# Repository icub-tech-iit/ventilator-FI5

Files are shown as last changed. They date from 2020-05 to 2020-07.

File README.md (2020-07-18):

FI5 Ventilator
==============
This repository contains the electronics of the ventilator.

### :file_folder: Folder organization
This repository is organized as follows:
- 🔘 `electrical_scheme` contains the electrical schematic of the ventilator (Logic diagram).
- 🔘 `electronic_boards` contains the OrCad schematics of the custom boards used in the ventilator, the gerber files for the PCBs, and the bill of material.
- 🔘 `wiring` contains the wiring diagram and the harness bill of material of the ventilator.

## Electronics repository
To correctly manage the large files stored within this repository, follow the [instructions to install Git LFS][1].

You can conveniently download the Electronics releases by visiting the [Release Page][2] 📦

[1]: https://help.github.com/en/articles/installing-git-large-file-storage
[2]: ../../releases

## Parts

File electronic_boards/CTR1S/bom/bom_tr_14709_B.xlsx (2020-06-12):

ID | IITCODE | N.P | QTY | REFDES | PACKAGE | CATEGORY | Value | Supply_voltage | Tolerance | Pieces_quoted | Description | Manuf | Manuf Code
1 | 579 |  | 1,00 | U4 | SOT23-5 | AO | LMC7101-BIM5 | 2.715V |  |  | Operational Amplifier, single, 2.715V supply voltage, rail to rail output swing, SMD, SOT23-5 | National Semiconductor | LMC7101-BIM5
2 | 14700 |  | 1,00 | U3 | 4132 | AP | 4132 |  |  |  | GPIO Expander module, 16 Additional IO over I2C, for Raspberry PI | Adafruit | 4132
3 | 14701 |  | 2,00 | U1 U5 | 3190 | AP | 3190 |  |  |  | Brushed DC Motor Driver Breakout, Adafruit | Adafruit | 3190
4 | 14703 |  | 1,00 | M7 | - | AP | STM32F746G-DISCO |  |  |  | ARM 32F746G, Discovery Kit ARMÂ® CortexÂ®-M7 Embedded Evaluation Board | St microelectronics | STM32F746G-DISCO
5 | 3 |  | 3,00 | C16 C15 C13 | 0603 | C | 100nF | 50V | 10% | X7R | Multilayer Ceramic Capacitor, 100nF, 50V, 10%, X7R, SMD, 0603 | Kemet | C0603C104K5RAC7867
6 | 652 |  | 1,00 | C14 | 0603 | C | 33nF | 50V | 5% | X7R | Multilayer Ceramic Capacitor, 33nF, 50V, 5%, X7R, SMD, 0603 | Avx | 06035C333JAT2A
7 | 7120 |  | 12,00 | C12 C11 C10 C9 C8 C7 C6 C5 C4 C3 C2 C1 | 0603 | C | 10nF | 25V | 5% | C0G | Multilayer Ceramic Capacitor, 10nF, 25V, 5%, C0G, SMD, 0603 | Kemet | C0603C103J3GACTU
8 | 274 |  | 5,00 | J24 J23 J22 J21 J20 | MKDS12-381 | CO | MKDS 12-3.81 | 12A |  |  | Terminal block, MKDS, 2 contacts, 1 row, female, p.3.81mm, Straight, w to b, 12A, screw terminal, THD | Phoenix | 1727010
9 | 275 |  | 2,00 | J28 J14 | MKDS13-381 | CO | MKDS 13-3.81 | 12A |  |  | Terminal block, MKDS, 3 contacts, 1 row, female, p.3.81mm, Straight, w to b, 12A, screw terminal, THD | Phoenix | 1727023
10 | 288 |  | 2,00 | J17 J5 | 53261-0471 | CO | 53261-0471 | 1A |  |  | PCB connector, Picoblade, 4 contacts, 1 row, male, p.1.25mm, 90Â°, w to b, lock, key, SMD | Molex | 53261-0471
11 | 504 |  | 3,00 | TP3 TP1 TP2 | TP-1206 | CO | S1751-46 |  |  |  | Test point, SMD, 1206 | Harwin | S1751-46
12 | 628 |  | 1,00 | J11 | PSTRIP5X1_M | CO | M20-9990545 | 3A |  |  | PCB connector, Pin strip, 5 contacts, 1 row, male, p.2.54mm, Straight, b to b, nolock, nokey, THD | Harwin | M20-9990545
13 | 709 |  | 3,00 | J32 J27 J18 | 53261-0871 | CO | 53261-0871 | 1A |  |  | PCB connector, Picoblade, 8 contacts, 1 row, male, p.1.25mm, 90Â°, w to b, nolock, key, SMD | Molex | 53261-0871
14 | 805 |  | 1,00 | J3 | PSTRIP6X1_M | CO | M20-9990645 | 3A |  |  | PCB connector, Pin strip, 6 contacts, 1 row, male, p.2.54mm, Straight, b to b, nolock, nokey, THD | Harwin | M20-9990645
15 | 1124 |  | 3,00 | J12 J9 J7 | 53261-0671 | CO | 53261-0671 | 1A |  |  | PCB connector, Picoblade, 6 contacts, 1 row, male, p.1.25mm, 90Â°, w to b, nolock, key, SMD | Molex | 53261-0671
16 | 1210 |  | 2,00 | J16 J6 | 53398-0471 | CO | 53398-0471 | 1A |  |  | PCB connector, Picoblade, 4 contacts, 1 row, male, p.1.25mm, Straight, w to b, nolock, key, SMD | Molex | 53398-0471
17 | 1388 |  | 3,00 | J13 J10 J8 | 53398-0671 | CO | 53398-0671 | 1A |  |  | PCB connector, Picoblade, 6 contacts, 1 row, male, p.1.25mm, Straight, w to b, nolock, key, SMD | Molex | 53398-0671
18 | 1391 |  | 2,00 | J31 J19 | 53398-0871 | CO | 53398-0871 | 1A |  |  | PCB connector, Picoblade, 8 contacts, 1 row, male, p.1.25mm, Straight, w to b, nolock, key, SMD | Molex | 53398-0871
19 | 12787 |  | 2,00 | J4 J1 | PSTRIP8X1_M | CO | M20-9990445 | 3A |  |  | PCB connector, Pin strip, 8 contacts, 1 row, male, p.2.54mm, Straight, b to b, nolock, nokey, THD | Harwin | M20-9990845
20 | 13911 |  | 1,00 | J2 | PSTRIP10X1_M | CO | TSW-110-07-G-S | 5.7A |  |  | PCB connector, Pin strip, 10 contacts, 1 row, male, p.2.54mm, straight, b to b, nolock, nokey, THD | Samtec | TSW-110-07-G-S
21 | 14713 |  | 2,00 | J30 J29 | - | COPF | 642-4957 | 1A |  |  | Flying connector, IDC, 16 contacts, 2 rows, female, p.2.54mm, Straight, w to w, no lock, key, 1A | RS | 642-4957
22 | 5126 |  | 1,00 | U8 | JHM10D | DC | JHM1012D05 | 10W | 10% |  | Insulated, DCDC converter, Vin 918V, Vout +-5V, 10W, insulation 4KVdc, THD, DIP, for medical use | Xp power | JHM1012D05
23 | 617 |  | 2,00 | D2 D1 | DO214AA | DI | SL22 | 2A |  |  | Diode schottky, Vrrm 20V, If 2A, Ifms 100A, SMD, DO214AA | Vishay | SL22
24 | 14710.0 |  | 1,00 | PCB |  | PCB | CTR1S_00 |  |  |  | CTR1S_00, IIT - Printed Circuit board | IIT | 14707
25 | 242 |  | 3,00 | R33 R32 R2 | 0603 | R | 0R | 0.063W | 1% | 200ppm | Resistor Thick film, 0R, 0.063W, 1%, SMD, 0603 | Multicomp | MC-0.063W-0603-0R
26 | 245 |  | 9,00 | R13 R14 R15 R19 R20 R21 R22 R23 R31 | 0603 | R | 1K | 0.1W | 1% | 100ppm | Resistor Thick Film, 1K, 0.1W, 1%, SMD, 0603 | Phycomp | 232270461002
27 | 447 |  | 2,00 | R16 R18 | 0603 | R | 220R | 0.1W | 1% | 100ppm | Resistor Thick film, 220R, 0.1W, 1%, SMD, 0603 | Phycomp | RC0603FR-07220RL
28 | 453 |  | 1,00 | R29 | 0603 | R | 1K2 | 0.1W | 1% | 200ppm | Resistor Thick film, 1K2, 0.1W, 1%, SMD, 0603 | Phycomp | RC0603FR-071K2L
29 | 454 |  | 1,00 | R30 | 0603 | R | 1K5 | 0.1W | 1% | 100ppm | Resistor Thick film, 1K5, 0.1W, 1%, SMD, 0603 | Phycomp | RC0603FR-071K5L
30 | 455 |  | 1,00 | R28 | 0603 | R | 2K2 | 0.1W | 1% | 100ppm | Resistor Thick film, 2K2, 0.1W, 1%, SMD, 0603 | Phycomp | RC0603FR-072K2L
31 | 462 |  | 1,00 | R27 | 0603 | R | 15K | 0.1W | 1% | 100ppm | Resistor Thick film 15K, 0.1W, 1%, SMD, 0603 | Phycomp | RC0603FR-0715KL
32 | 1574 |  | 11,00 | R5 R6 R7 R8 R9 R10 R11 R17 R24 R34 R35 | 0603 | R | 10K | 0.063W | 1% | 100ppm | Resistor Thick film, 10K, 0.063W, 1%, SMD, 0603 | Multicomp | MC 0.063W 0603 1% 10K
33 | 12058 |  | 4,00 | R42 R43 R44 R45 | 6.3X2.3 | R | 100R | 0.5W | 5% | 700ppm | Resistor Carbon film, 100R, 0.5W, 5%, THD, Diam 6.3x2.3mm | RS | 707-8142
34 | 14702 |  | 1,00 | U2 | 1536 | SE | Buzzer 5V |  |  |  | Miniature piezo buzzer, for Adafruit breadboard, 2kHz, 35V, THD | Adafruit | 1536
35 | 5232 | X | 25,00 | TP28 TP25 TP26 TP27 TP23 TP24 TP20 TP21 TP22 TP18 TP19 TP15 TP16 TP17 TP13 TP14 TP10 TP11 TP12 TP8 TP9 TP5 TP6 TP7 TP4 | TP-ATE, TP-ATE-TH, TP-ATE-SMALL, TP-ATE_1MM | CO | TEST POINT 3mm |  |  |  | Test point, PCB, round, 3mm, for automatic test equipment | IIT | 5232
36 | 4270 | X | 4,00 | H4 H3 H2 H1 | MH3 | FAST | M3 Metallized hole |  |  |  | PCB hole, metallized, for M3 thread | IIT | 4270
37 | 242 | X | 6,00 | R37 R38 R39 R40 R41 R4 | 0603 | R | 0R | 0.063W | 1% | 200ppm | Resistor Thick film, 0R, 0.063W, 1%, SMD, 0603 | Multicomp | MC-0.063W-0603-0R
38 | 289 | X | 1,00 | R1 | 0805 | R | 0R | 0.125W | 1% | 200ppm | Resistor Thick Film, 0R, 0.125W, 1%, SMD, 0805 | Phycomp | 232273091002

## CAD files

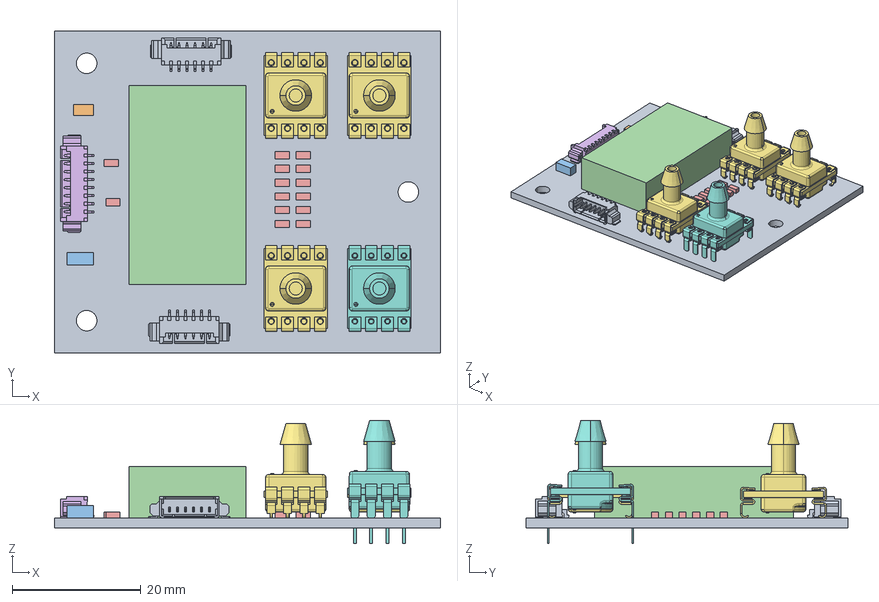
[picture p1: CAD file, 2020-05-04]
electronic_boards/CTR1P/mcad/CTR1P_00.stp
60.0 x 50.0 x 19.2 mm
ASM0002
TP-1206
PICOBLADE-8X1-MALE90-P125
HSCMAND160MD2A5 x 3
HSCDANN150PG2A5
PICOBLADE-6X1-MALE90-P125 x 2

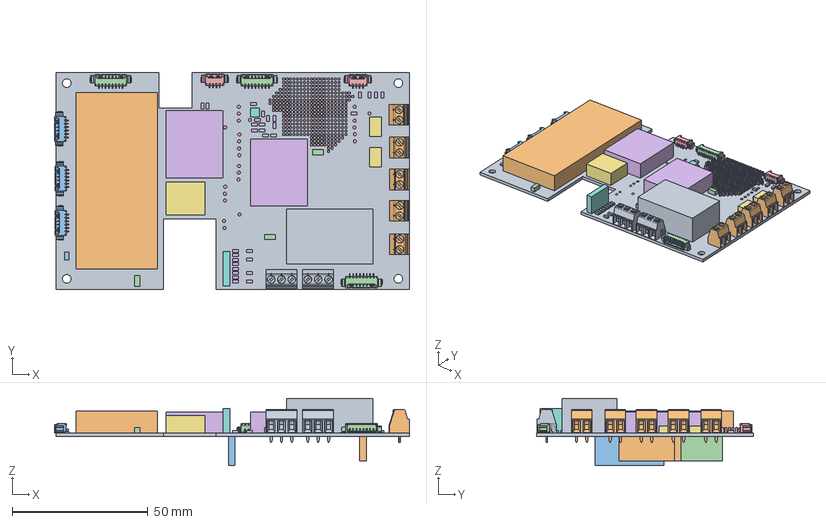
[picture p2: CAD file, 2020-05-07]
electronic_boards/CTR1S/mcad/CTR1S.stp
130.6 x 80.0 x 24.8 mm
PCB_CTR1S_00_MECH
PSTRIP8X1_M x 2
PSTRIP10X1_M
PSTRIP6X1_M
TP-ATE-TH x 369
DO214AA x 2
PSTRIP5X1_M
MKDS13-381 x 2
MKDS12-381 x 5
TP-1206 x 3
TP-ATE x 25
SOT23-5
JHM10D
PICOBLADE-6X1-MALE90-P125 x 3
PICOBLADE-8X1-MALE90-P125 x 3
PICOBLADE-4X1-MALE90-P125 x 2

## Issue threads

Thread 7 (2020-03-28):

Define the power supply

MrAndrea, 2020-03-28:
Ventilator needs a power supply. In this issue we collect proposals to find a good solution.
Action points:
- [ ] estimate the power consumption of the ventilator
- [x] evaluate battery solution / UPS for backup of the mains voltage
- [ ] other (WIP)

maggia80, 2020-05-27:
we need to change the value of R28 for setting the shutdown threshold

R28 was 51k become 82k

maggia80, 2020-05-27:
R10 and R11 are now 51k. Now the battery voltage and the output voltage is 13.60V.

MrAndrea, 2020-05-28:
I added the charger on the logic schematic, @maggia80 is the connection corresponding to the cabling?

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

MrAndrea, 2020-06-25:
`Rev 0.0.6` (logic and harness) contains the charger connections as proposed in the [previous comment](https://github.com/icub-tech-iit/ventilator-FI5/issues/7#issuecomment-635360759).

Closed 2023-01-04.

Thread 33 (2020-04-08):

FW design and implementation notes

andreamerello, 2020-04-08:
In this issue we are going to publishing some misc notes we wrote in EDL regarding firmware design and implementation proposal. They include architectural aspects and notes about HW configuration.

They are still **draft**, but we would like to start sharing something; they are about the low level part (sensor reading/pwm generation).

pattacini, 2020-05-13:
We're certainly done with this, you guys having done a great job 👍
Further refinements and bug fixes can be conveniently made in dedicated issues.

Closed 2020-05-13.

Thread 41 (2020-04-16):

Design the electrical schematic with Capital

MrAndrea, 2020-04-16:
This issue to create and describe the electrical schematic of the ventilator using Mentor Capital.

MrAndrea, 2022-10-19:
I think we can close this issue.

Closed 2022-10-19.

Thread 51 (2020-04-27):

Alarms to be implemented in FSM

simeonedussoni, 2020-04-27:
Here we collect needed alarms to be implemented in the ventilator. Related signals, sensors etc. will be read by a dedicated FSM which will be in charge of generating the corresponding buzzer/light conditions as well as to pass infos to the controller. Many alarms are already discussed in several places.

simeonedussoni, 2021-11-05:
project closed, I close also the issue.

Closed 2021-11-05.

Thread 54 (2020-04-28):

Create BOMs

MrAndrea, 2020-04-28:
In this issue we collect the BOMs of the ventilator for the electronics and the wiring as the work progresses.
The BOMs will be upload on Wingst with the respective IITCODE.

Closed 2020-05-13.

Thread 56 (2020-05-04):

Develop GUI menu dialogs

Nicogene, 2020-05-04:
# Task description
This issue keeps track of the development of the menu functionalities for the ventilator GUI.

# Definition of Done
The menu functionalities are fully implemented.

pattacini, 2020-05-24:
Instead of using the touch screen, we need to anchor the menu dialogs to the use of the multi-selector encoder. The tags and the ranges of the dialog options can be retrieved by inspecting the FSM.

Closed 2023-01-04.

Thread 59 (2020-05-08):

Download data from FI5 to do comparative analyses

pattacini, 2020-05-08:
We need to download experimental data from FI5 in order to be able to carry out extensive analyses to validate the device and the simulation predictions.

@marcoaccame can this be done relying merely on the debugger or do we need to design some sort of rudimental acquisition layer?

marcoaccame, 2020-05-13:
Hi @pattacini, we don't need to buffer data in RAM.

We have two solutions:
- use the trace port, which I have already used to print data at every 10 ms. it is textual data which i can format as i like.
- use the usart with an increased sped. i have just tested a speed of  20x=112500 and I read correctly w/ putty.

In following days I will write and test a proper data dumper.

marcoaccame, 2020-06-17:
just committed code for performing data log: https://github.com/icub-tech-iit/ventilator-FI5/commit/979b7d7a203667c4bb624f9fec48b8f96b6cc722. it is possible to use either trace port of usart @ 4mbps.
tests + data collection: tomorrow.

pattacini, 2020-06-18:
Analyses carried out in #60 confirm that this acquisition methodology is effective and up to the task.

@marcoaccame we can close this, I reckon.

Closed 2020-06-18.

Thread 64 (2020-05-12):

Error in BIVAR CODE for yellow and green panel LEDs in partlist

claudiolorini, 2020-05-12:
~~Partlist~~

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

pattacini, 2020-05-13:
@claudiolorini just a brief note: now that the repo's been made public we should no longer post links to restricted resources. Thus, I've edited your OP above with a screenshot (the quickest solution that I had).

claudiolorini, 2020-05-14:
whoever compiled the partlist, i suppose @Fabrizio69? btw after some navigation in the project (tree and branches) i wasn't able to find the position of the partlist in the git repository, a more visible handle can be advantageous...

pattacini, 2020-05-14:
Given the [structure of the repo][1], the [BOM][2] is located in the `mech` branch, if that is the resource you meant.

At any rate, we should devote some effort to enrich the repo with `README.md` files describing the resources we made openly available as we've just gone public. In this sense, yep, we kind of still lack this type of documentation.

Anyway, @Fabrizio69 would you be willing to fix this bug in the BOM? Be careful as the `mech` branch is revisioned under Git LFS, although Excel files are not tracked by LFS (yet).

[1]: ../../ventilator-FI5#-repository-structure
[2]: https://github.com/icub-tech-iit/ventilator-FI5/blob/mech/Ventilator%20FI5%20BOM%20Rev0.xlsx

maggia80, 2020-05-20:
I have updated the BOM:

https://github.com/icub-tech-iit/ventilator-FI5/blob/mech/Ventilator%20FI5%20BOM%20Rev0.xlsx

I didn't change the revision, because there was only the description wrong but the part numbers were correct

Closed 2020-05-20.

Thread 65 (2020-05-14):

Plotting slows down at the end of the drawing canvas

Nicogene, 2020-05-14:
We noticed that at the end of the graph the draw of the points seems to slow down.
The plot is done in this way:

```
CoordList.AddCoord( float(plotIndex), -valY);
Graph.Coordinates = CoordList;
```

My hyposthesis is that every iteration `CoordList` become bigger and bigger and the `Graph.Coordinates = CoordList;` copy become more and more expensive. Unfortunately @vtikha and me tried to reduced the number of point plotted, and to plot in a more efficient way, but also checking online it seems to be the only way it work.
(For example see https://ask.embedded-wizard.de/2931/how-to-avoid-drawing-a-graph-outside-of-the-window)

However, before proceeding with a deep refactoring in order to optimize it, I would measure the time that every iteration the gui takes for plotting the data, in order to see if it actually slows down or it was just an impression.

In this sense we failed to do it inside Embedded Wizard, it would be way simpler to do `tic-toc` before and after the call `EwProcess()` inside the firmware.
For this we may have the need of help of @marcoaccame .

marcoaccame, 2020-05-14:
ok @Nicogene, I have an idea of how to measure it. i will write some code which we should test on the prototype.

the idea is to log time before and after in a non intrusive way, measure an histogram and the print it now and then on trace port or on usart.

or ... we just could look at something like what I measured for demo013 just yesterday.
https://github.com/icub-tech-iit/ventilator-FI5/blob/code/tests/boards/stm32f7disco/demo013/instructions/assets/prcv.10ms.timeHMI.jpg

the botton labeled `<No Address> (6)` is teh scheduling of the thread HMI

marcoaccame, 2020-05-14:
Hi @Nicogene,
I have just committed https://github.com/icub-tech-iit/ventilator-FI5/commit/60d6132725f326fbb301fe5b09cae18b0754a8eb. it gives support for printing every 5 seconds on teh trace port the statistics (histogram between 30 and 80 ms) of the duration of the execution of `EwProcess()`. And also, if required, the print of each duration time.

We can test it next time we work on the prototype.

Nicogene, 2020-05-14:
Where it is printed out?

marcoaccame, 2020-05-15:
> Where it is printed out?

so far on the trace port which is captured by u-Vision and displayed by the `Debug (printf) Viewer`.
You enable the display as shown by the following picture (of another project as I don't have the ventilator board w/ me).

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

**Remember**: you must define macro HMI_PRINTS in file `tests/boards/stm32f7disco/demo013/code/iit/app_tHMI.cpp` (or in the whole project).

Closed 2023-01-04.

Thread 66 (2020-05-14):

VX-209573- FITTING G1/2MALE-CONIC 22M

maggia80, 2020-05-14:
The part VX-209573 has the inner part that doesn't let the 15mm male to be plugged

see the picture below:
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

cc: @fbiggi @mgentili81

maggia80, 2020-05-14:
we should increase the ID in the: https://github.com/icub-tech-iit/ventilator-FI5/blob/mech/drawings/VX-209573_1.pdf

Closed 2023-01-04.

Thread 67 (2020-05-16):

Missing Drawings

pattacini, 2020-05-16:
@mariovillalon from Mexico (where they aim to reproduce our FI5 prototype) forwarded us the following request:

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

MISSING DRAWINGS OR TECHNICAL CHECK SHEET | MISSING NUMBER IN BOM
-- | --
VX-209515 | VX-209628
VX-209522 | VX-209631_1
VX-209583 | VX-209632_1
VX-209584 | VX-209635_1
VX-209585 | VX-209637_1
VX-209590 | VX-209639_1
VX-209594 | VX-209640_1
VX-209651 |  
VX-209750 |  
VX-209751 |  
VX-209648 |  
VX-209649 |  
VX-209652 |  
VX-209653 |  
VX-209655 |  
VX-209656 |  
VX-209658 |  
VX-209659 |  
VX-209705 |  
VX-209737 |  
VX-209744 |  
VX-209752 |  

cc @maggia80 @Fabrizio69

maggia80, 2020-05-16:
MISSING DRAWINGS OR TECHNICAL CHECK SHEET | NOTE
-- | --
VX-209515 | it's a 3D printed part. The drawing is missing, we will add it, but meanwhile, you can create the STL file from the .stp that you find in the https://github.com/icub-tech-iit/ventilator-FI5/blob/mech/VX-209503.stp 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
VX-209522 | cable check the harness drawing and BOM https://github.com/icub-tech-iit/ventilator-FI5/tree/ele/wiring
VX-209583 | cable check the harness drawing and BOM https://github.com/icub-tech-iit/ventilator-FI5/tree/ele/wiring
VX-209584 | cable check the harness drawing and BOM https://github.com/icub-tech-iit/ventilator-FI5/tree/ele/wiring
VX-209585 | cable check the harness drawing and BOM https://github.com/icub-tech-iit/ventilator-FI5/tree/ele/wiring
VX-209590 | cable check the harness drawing and BOM https://github.com/icub-tech-iit/ventilator-FI5/tree/ele/wiring
VX-209594 | cable check the harness drawing and BOM https://github.com/icub-tech-iit/ventilator-FI5/tree/ele/wiring
VX-209651 | cable check the harness drawing and BOM https://github.com/icub-tech-iit/ventilator-FI5/tree/ele/wiring
VX-209750 | cable check the harness drawing and BOM https://github.com/icub-tech-iit/ventilator-FI5/tree/ele/wiring
VX-209751 | cable check the harness drawing and BOM https://github.com/icub-tech-iit/ventilator-FI5/tree/ele/wiring
VX-209648 | cable check the harness drawing and BOM https://github.com/icub-tech-iit/ventilator-FI5/tree/ele/wiring
VX-209649 | cable check the harness drawing and BOM https://github.com/icub-tech-iit/ventilator-FI5/tree/ele/wiring
VX-209652 | cable check the harness drawing and BOM https://github.com/icub-tech-iit/ventilator-FI5/tree/ele/wiring
VX-209653 | cable check the harness drawing and BOM https://github.com/icub-tech-iit/ventilator-FI5/tree/ele/wiring
VX-209655 | cable check the harness drawing and BOM https://github.com/icub-tech-iit/ventilator-FI5/tree/ele/wiring
VX-209656 | cable check the harness drawing and BOM https://github.com/icub-tech-iit/ventilator-FI5/tree/ele/wiring
VX-209658 | cable check the harness drawing and BOM https://github.com/icub-tech-iit/ventilator-FI5/tree/ele/wiring
VX-209659 | cable check the harness drawing and BOM https://github.com/icub-tech-iit/ventilator-FI5/tree/ele/wiring
VX-209705 | cable check the harness drawing and BOM https://github.com/icub-tech-iit/ventilator-FI5/tree/ele/wiring
VX-209737 | cable check the harness drawing and BOM https://github.com/icub-tech-iit/ventilator-FI5/tree/ele/wiring
VX-209744 | cable check the harness drawing and BOM https://github.com/icub-tech-iit/ventilator-FI5/tree/ele/wiring
VX-209752 | cable check the harness drawing and BOM https://github.com/icub-tech-iit/ventilator-FI5/tree/ele/wiring
VX-209628 | this code is not present in VX-209503.stp
VX-209631_1 | parts for Manifold pressure test (not required for the prototype)
VX-209632_1 | parts for Manifold pressure test (not required for the prototype)
VX-209635_1 | parts for Manifold pressure test (not required for the prototype)
VX-209637_1 | parts for Manifold pressure test (not required for the prototype)
VX-209637_1 | parts for Manifold pressure test (not required for the prototype)
VX-209639_1 | parts for Manifold pressure test (not required for the prototype)
VX-209640_1 | parts for Manifold pressure test (not required for the prototype)

maggia80, 2020-05-16:
@MarioVillalon let me know if there is something unclear or if you need further info.

MarioVillalon, 2020-05-16:
Gracias Marco, probaremos y te comento.

Saludos

Il giorno sab 16 mag 2020 alle ore 09:49 marco maggiali <
notifications@github.com> ha scritto:

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

maggia80, 2020-05-18:
@MarioVillalon we uploaded the missing drawing and we added the STL files for 3D printed parts.

pattacini, 2020-05-18:
@MarioVillalon for your convenience, you can download the latest `mech` release from here: https://github.com/icub-tech-iit/ventilator-FI5/releases/tag/mech-v1.0.1.

MarioVillalon, 2020-05-18:
Great Ugo, Thanks.

Best regards

Il giorno lun 18 mag 2020 alle ore 10:45 Ugo Pattacini <
notifications@github.com> ha scritto:

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

MarioVillalon, 2020-05-27:
Ciao Ugo, hi Marco

Is it possible to get de document “FI5-specs.pdf” in Italian?

Enviado desde mi iPhone

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

pattacini, 2020-05-27:
Hi @MarioVillalon

Unfortunately, we don't have it in Italian.

MarioVillalon, 2020-05-27:
Ok Ugo, thanks anyways

Regards

Il giorno mer 27 mag 2020 alle ore 13:29 Ugo Pattacini <
notifications@github.com> ha scritto:

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

Closed 2020-06-02.

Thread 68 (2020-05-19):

Flow-by not working on the device

pattacini, 2020-05-19:
From the visual inspection of the GUI during preliminary tests, I didn't see flow-by (see #61) working as expected on the physical ventilator, although in the simulator it was spot on.

Further debugging is thus required.

pattacini, 2020-06-18:
Actually, from a deep inspection of the quantities logged directly from the device, it came out that the flow-by is perfectly working 👍

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

Closed 2020-06-18.

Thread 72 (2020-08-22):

Integrate TV Correction into FW

pattacini, 2020-08-22:
Hi @marcoaccame 👋🏻

Because I've developed a new functionality regarding the `TV Correction` in VCV mode (see #70 and #71), I'd like to ask you to integrate the enclosed generated code (see the archives below) in the latest FW version. This will also allow us to churn out a new overall release.

⚠Be careful since one more parameter (i.e. `TV_correction_gain_Value`) can be now tuned as the 4th element of the `MAP_Transfer_Advanced` Map (former `MAP_Transfer_AutoTrigger`): for details, please look over https://github.com/icub-tech-iit/ventilator-FI5/pull/71/files.

In particular, you have to replace the following snippet
https://github.com/icub-tech-iit/ventilator-FI5/blob/37436da61d062aea663ea967e673d40a26284160/application/code/app/fi5app_theController2.cpp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
with:
```diff
- case MAP_Transfer_AutoTrigger:
+ case MAP_Transfer_Advanced:
   {
       parameters.enable_trigger_Value = (outputs.knobs_out[0] > 0.5);
       parameters.pressure_thres_const = outputs.knobs_out[1];
       parameters.flowby_target_Value = outputs.knobs_out[2];
+      parameters.TV_correction_gain_Value = outputs.knobs_out[3];
   } break;
```

### 📦 Generate Code
- [controller.zip](https://github.com/icub-tech-iit/ventilator-FI5/files/5112916/controller.zip)
- [fsm.zip](https://github.com/icub-tech-iit/ventilator-FI5/files/5112917/fsm.zip)

pattacini, 2020-09-03:
Correct 👍🏻
Nice catch!

marcoaccame, 2020-09-03:
ok. i'll commit and push then

marcoaccame, 2020-09-03:
pushed in https://github.com/icub-tech-iit/ventilator-FI5/commit/e91e75036b6ee8d9a09b74a20c8f6629de08d1b3

pattacini, 2020-09-03:
Thanks!

Closed 2020-09-03.

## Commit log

2020-05-04 files copied in the right branch
    [CTR1P_00.stp, SE_CTR1P_00.DSN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]
2020-05-07 CTR1S Controller Shield board
    [CTR1S.stp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]
2020-05-07 renaming CTR1P
    [CTR1P_00.stp, SE_CTR1P_00.DSN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]
2020-05-07 added board pictures
2020-05-07 renaming folder
    [CTR1P_00.stp, CTR1S.stp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]
2020-05-13 Harness BOM rev 0.0.5
    [Ventilator FI5 -Harness - BOM Rev0.0.5.xlsx]
2020-05-13 harness BOM
    [Ventilator FI5 -Harness - BOM Rev0.0.5.xlsx]
2020-05-13 Project name corrected
    [Ventilator FI5 - Harness - BOM Rev0.0.5.xlsx, Ventilator FI5 -Harness - BOM Rev0.0.5.xlsx]
2020-06-08 bom in csv format
    [bom_tr_14708_A.csv]
2020-06-12 xlsx version
    [bom_tr_14709_B.xlsx]
2020-06-12 xls version
    [bom_tr_4708_A.xlsx]
2020-06-12 fixed file name
    [bom_tr_14708_A.xlsx, bom_tr_4708_A.xlsx]
2020-06-25 capital logic and harness schematics updated to re. 0.0.6
